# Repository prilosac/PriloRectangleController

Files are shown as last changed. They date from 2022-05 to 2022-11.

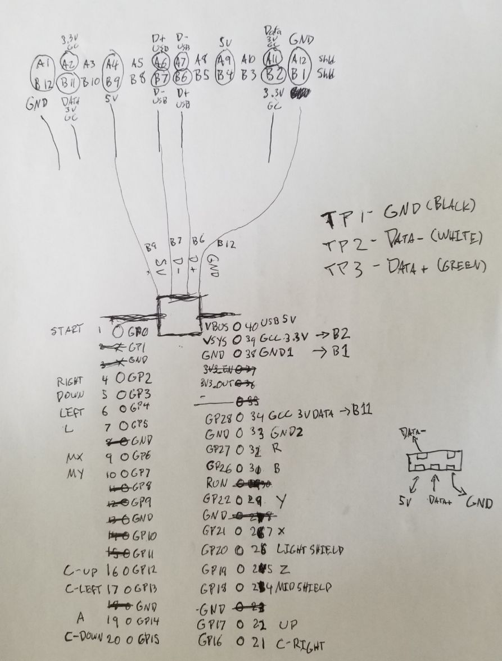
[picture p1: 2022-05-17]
RPiPico-USBC.jpg

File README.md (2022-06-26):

# PriloRectangleController
A digital controller PCB/chassis design meant to be easy to order and assemble while remaining a professional feeling and relatively customizable product.

HEAVILY inspired by GCCMX from Crane1195, which this repository was forked from.

ToDo: Replace these images with images made from this repository's files (these are from Crane's original repo)




The PCB is design to allow easy surface mount soldering of a Raspberry Pi Pico, the preferred board for DIY rectangle controllers in the community currently. It is also designed to easily solder a [Model U](https://github.com/Crane1195/Model-U) to with headers.

Credit to RMZ Customs for the hand drawn Pico diagram, and Austin for the modified Pico kicad files (and for lots of help in general).

## Parts:
1. [2.54mm pitch low profile header](https://www.digikey.com/en/products/detail/samtec-inc/TLW-136-05-T-S/1105024) (allows for thinner rectangle. alternatively use regular (2.50mm insulatio height) headers and allow for an extra 0.98mm of clearance in the case)
2. [M6 size fastener bolts](https://www.amazon.com/gp/product/B07QF7VB9P/ref=ppx_yo_dt_b_asin_title_o00_s00?ie=UTF8&th=1)

## License
This project is licenced under the GNU GPL Version 3. [See the included LICENSE file for details](LICENSE).

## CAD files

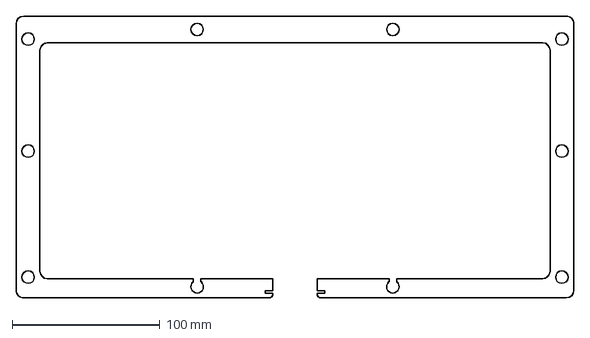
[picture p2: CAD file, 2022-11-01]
src/chassis/4+5_GenericWallLayer-USBCCutout.dxf
377.2 x 190.6 mm

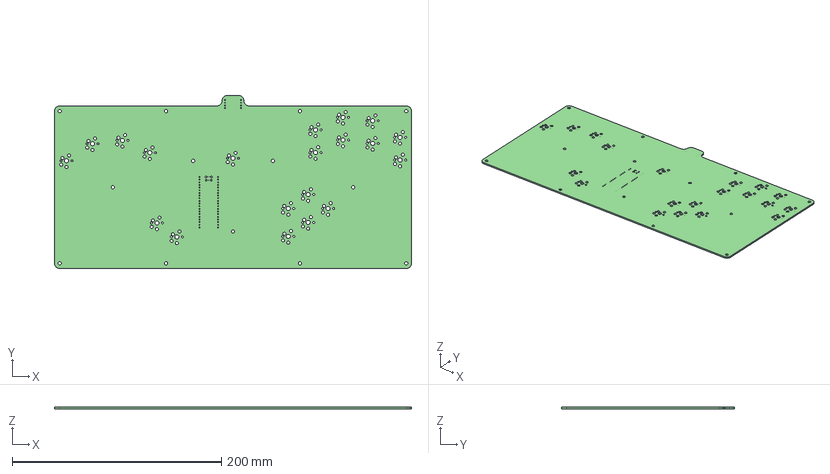
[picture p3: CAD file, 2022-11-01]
src/pcb/GCCMX.step
341.2 x 165.5 x 1.60 mm

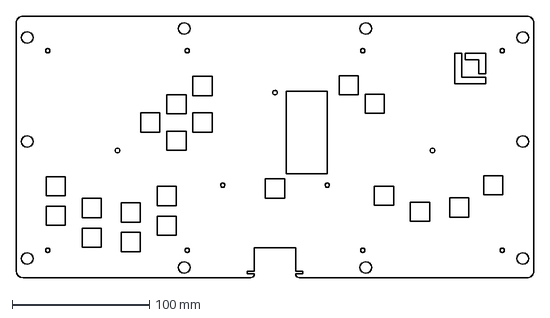
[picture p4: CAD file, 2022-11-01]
src/chassis/3_SwitchPlateOneStartPicoCutout.dxf
377.2 x 190.6 mm

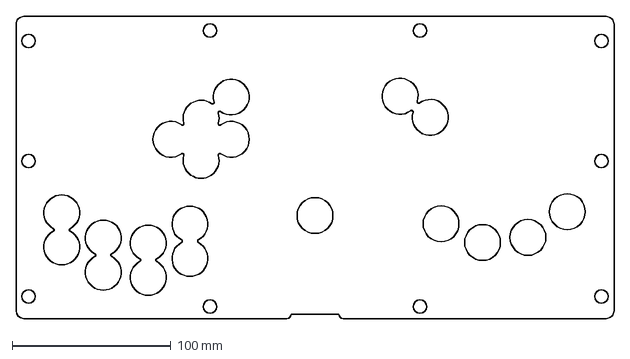
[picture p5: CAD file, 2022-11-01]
src/chassis/1_GFCoverOneStart.dxf
377.2 x 190.6 mm

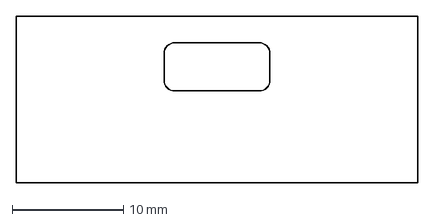
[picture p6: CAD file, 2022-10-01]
src/chassis/USBC_Cutout.dxf
36.0 x 14.9 mm

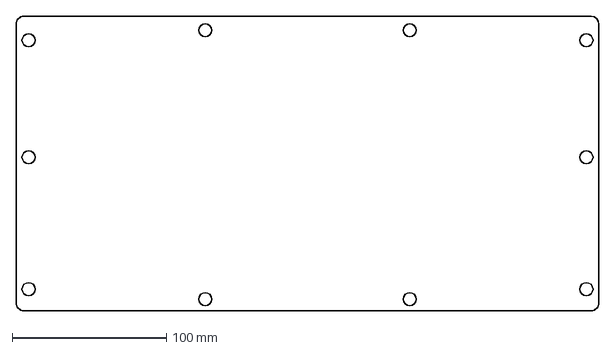
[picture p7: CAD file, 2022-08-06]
src/chassis/6_Bottom.dxf
377.2 x 190.6 mm

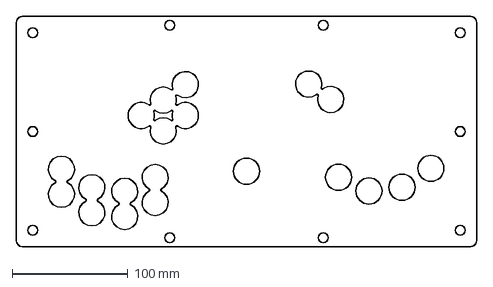
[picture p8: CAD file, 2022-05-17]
src/chassis/1_GFCoverOneStartWithFloatingPiece.dxf
397.2 x 198.6 mm

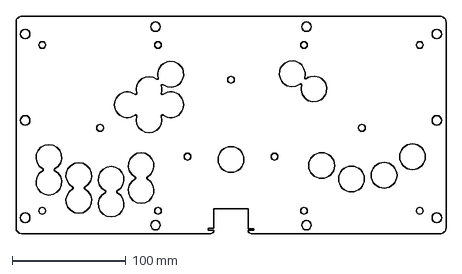
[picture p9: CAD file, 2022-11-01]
src/chassis/1_GFCoverOneStartBottomSwitchplateScrewHoles.dxf
377.2 x 190.6 mm

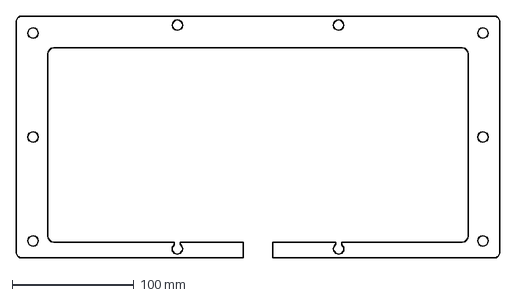
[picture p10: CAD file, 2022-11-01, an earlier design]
src/chassis/old/4+5_GenericWallLayer.dxf
397.2 x 198.6 mm

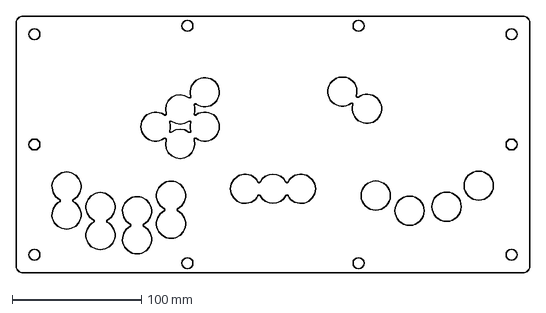
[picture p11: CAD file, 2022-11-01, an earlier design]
src/chassis/old/1_GFCover.dxf
397.2 x 198.6 mm

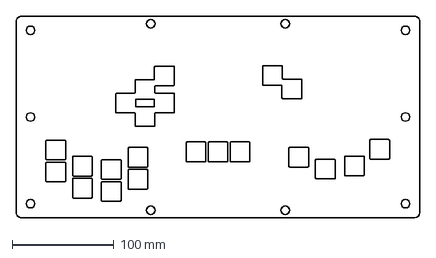
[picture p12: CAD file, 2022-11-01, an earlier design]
src/chassis/old/1_SquareCover.dxf
397.2 x 198.6 mm

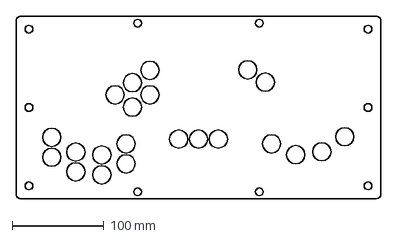
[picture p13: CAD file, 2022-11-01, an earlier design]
src/chassis/old/1_SmallCover.dxf
397.2 x 198.6 mm

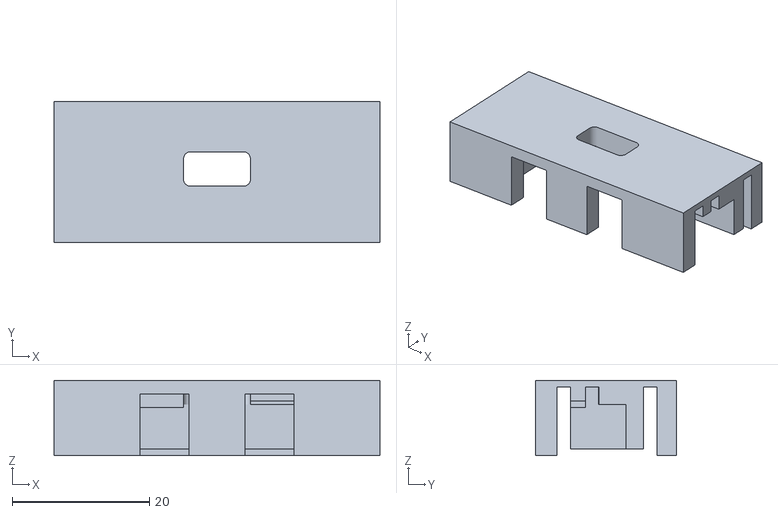
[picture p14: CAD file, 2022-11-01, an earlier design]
src/chassis/old/ModelS_USBC_Cover.stl
47.5 x 20.5 x 11.0

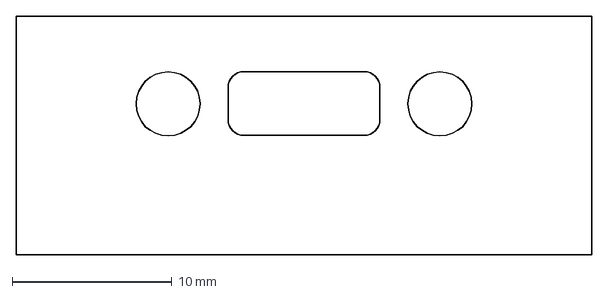
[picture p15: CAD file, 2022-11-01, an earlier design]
src/chassis/old/USBC_CutoutOLD.dxf
36.0 x 14.9 mm

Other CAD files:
src/chassis/old/3_SwitchPlate.dxf
src/chassis/old/4_GCCMXCover.dxf
src/chassis/old/5_ModelSCover.dxf

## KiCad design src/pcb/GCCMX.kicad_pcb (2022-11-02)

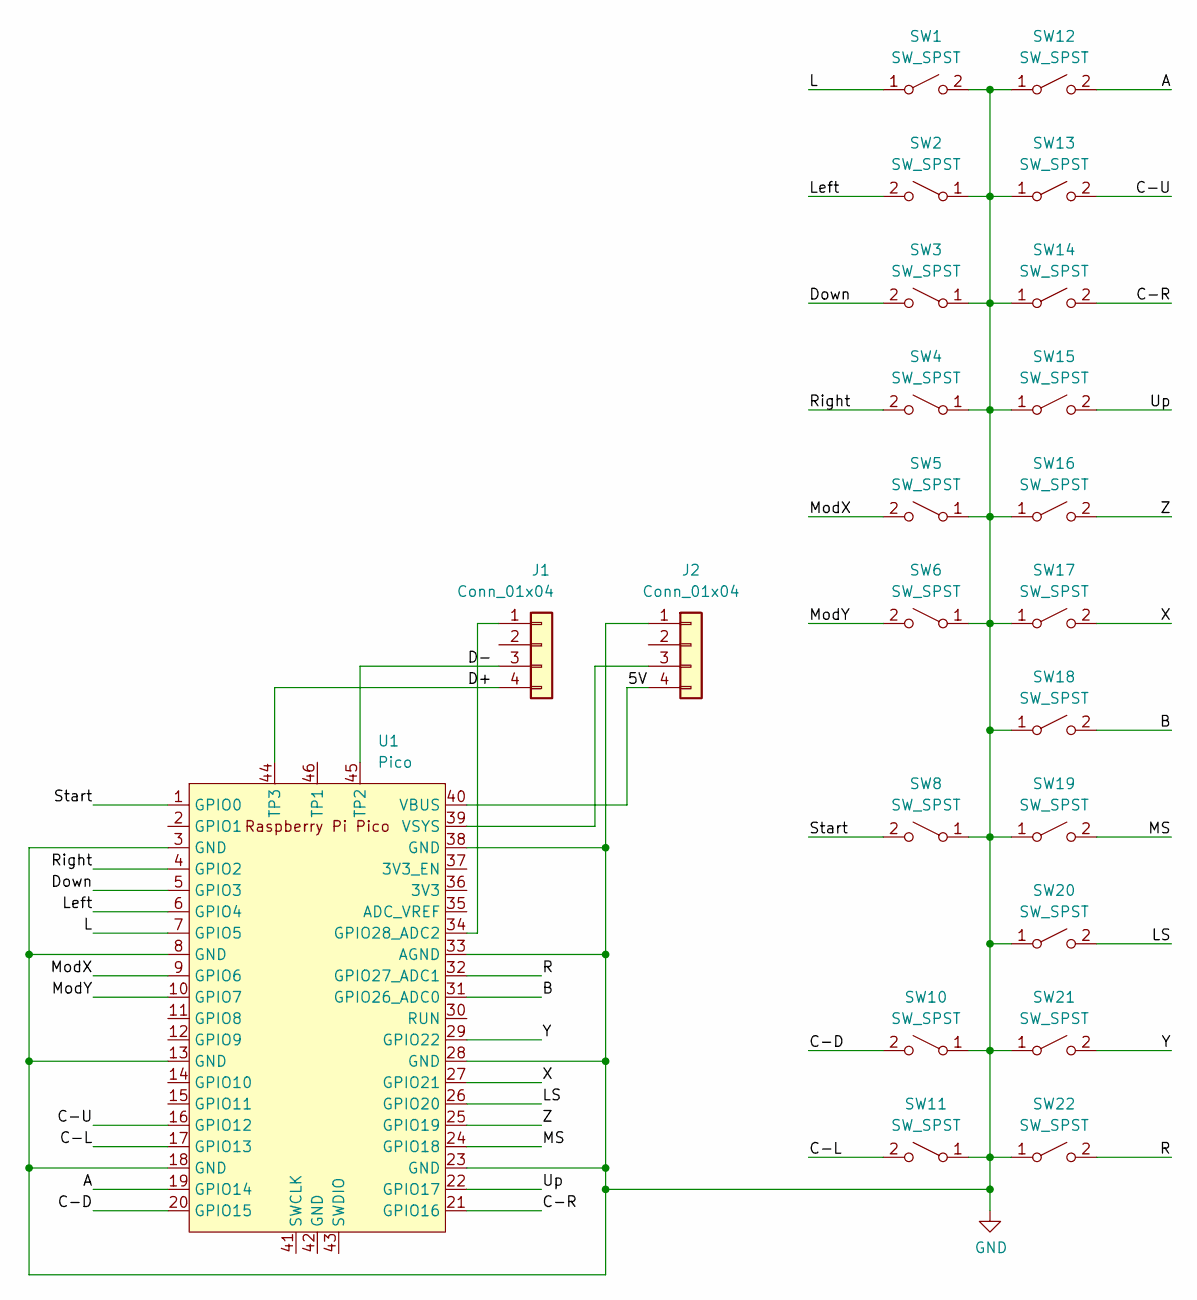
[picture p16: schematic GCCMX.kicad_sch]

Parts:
J1, J2: Conn_01x04; PinHeader_1x04_P2.54mm_Vertical
SW1, SW2, SW3, SW4, SW5, SW6, SW8, SW10, SW11, SW12, SW13, SW14, SW15, SW16, SW17, SW18, SW19, SW20, SW21, SW22: SW_SPST; Kailh_socket_MX+PG1350
U1: Pico; RPi_Pico_Removed3Pins

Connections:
/5V: J2.4, U1.40 (VBUS)
/A: SW12.2 (B), U1.19 (GPIO14)
/B: SW18.2 (B), U1.31 (GPIO26_ADC0)
/C-D: SW10.2 (B), U1.20 (GPIO15)
/C-L: SW11.2 (B), U1.17 (GPIO13)
/C-R: SW14.2 (B), U1.21 (GPIO16)
/C-U: SW13.2 (B), U1.16 (GPIO12)
/D+: J1.4, U1.44 (TP3)
/D-: J1.3, U1.45 (TP2)
/Down: SW3.2 (B), U1.5 (GPIO3)
/L: SW1.1 (A), U1.7 (GPIO5)
/LS: SW20.2 (B), U1.26 (GPIO20)
/Left: SW2.2 (B), U1.6 (GPIO4)
/MS: SW19.2 (B), U1.24 (GPIO18)
/ModX: SW5.2 (B), U1.9 (GPIO6)
/ModY: SW6.2 (B), U1.10 (GPIO7)
/R: SW22.2 (B), U1.32 (GPIO27_ADC1)
/Right: SW4.2 (B), U1.4 (GPIO2)
/Start: SW8.2 (B), U1.1 (GPIO0)
/Up: SW15.2 (B), U1.22 (GPIO17)
/X: SW17.2 (B), U1.27 (GPIO21)
/Y: SW21.2 (B), U1.29 (GPIO22)
/Z: SW16.2 (B), U1.25 (GPIO19)
GND: J2.1, SW1.2 (B), SW2.1 (A), SW3.1 (A), SW4.1 (A), SW5.1 (A), SW6.1 (A), SW8.1 (A), SW10.1 (A), SW11.1 (A), SW12.1 (A), SW13.1 (A), SW14.1 (A), SW15.1 (A), SW16.1 (A), SW17.1 (A), SW18.1 (A), SW19.1 (A), SW20.1 (A), SW21.1 (A), SW22.1 (A), U1.3 (GND), U1.8 (GND), U1.13 (GND), U1.18 (GND), U1.23 (GND), U1.28 (GND), U1.33 (AGND), U1.38 (GND)
unnamed: J1.1, U1.34 (GPIO28_ADC2)
unnamed: J2.3, U1.39 (VSYS)

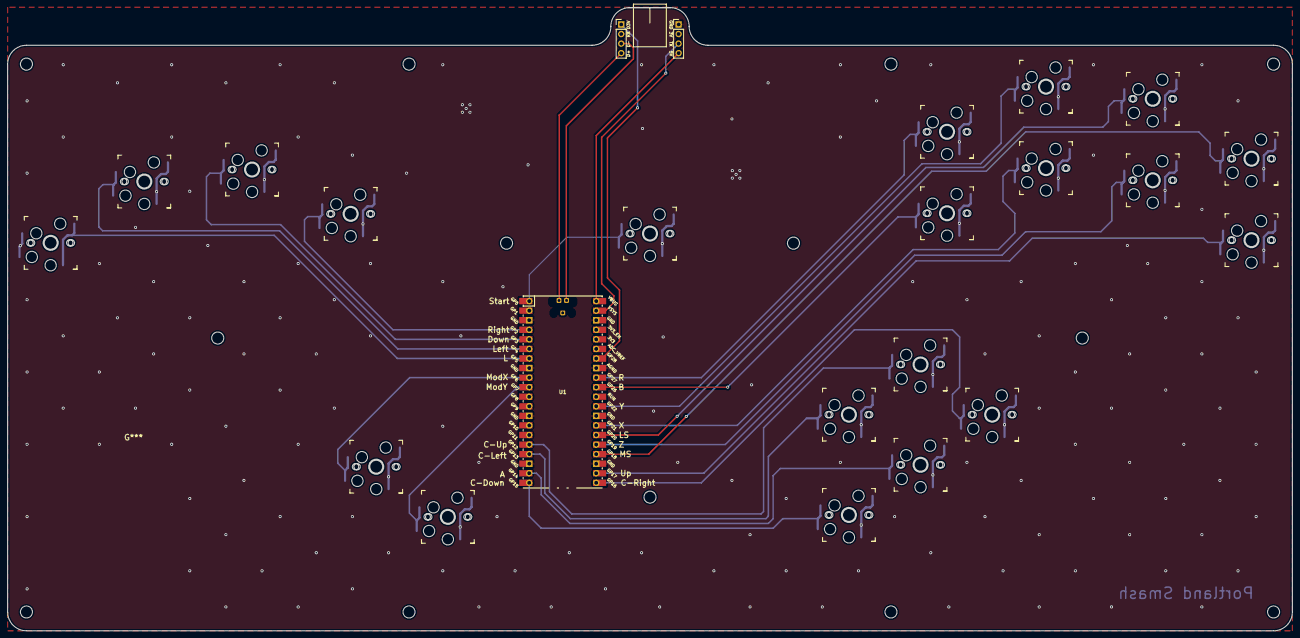
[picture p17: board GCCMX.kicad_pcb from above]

Board: 2 copper layers, 341.2 x 165.5 mm, 23 parts (0 on the bottom side), 26 nets.

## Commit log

2022-05-17 pushing everything up from prior work
    [1_GFCoverOneStart.dxf, 1_GFCoverOneStartBottomSwitchplateScrewHoles.dxf, 1_GFCoverOneStartWithFloatingPiece.dxf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]
2022-06-26 updated wall layers and usbc for a bit more support
    [4+5_GenericWallLayer-USBCCutout.dxf, USBC_Cutout.dxf]
2022-08-06 updated pcb, moved USB to front so we no longer require a separate passthrough cable
    [GCCMX-B_Cu.gbl, GCCMX-B_Mask.gbs, GCCMX-B_Paste.gbp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]
2022-08-06 reduced overall size of case by 20mm horizontally and 8mm vertically, adjusted fastener bolt holes in accordance.
    [1_GFCoverOneStart.dxf, 1_GFCoverOneStartBottomSwitchplateScrewHoles.dxf, 3_SwitchPlateOneStartPicoCutout.dxf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]
2022-11-01 looots of case updates. just need to flip the model UD from the back to the front and im ready to test v3 i think
    [1_GFCover.dxf, 1_GFCoverOneStart.dxf, 1_GFCoverOneStartBottomSwitchplateScrewHoles.dxf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]
2022-11-02 updated PCB to have model UD on top, regenerated fab files
    [GCCMX-B_Cu.gbl, GCCMX-B_Mask.gbs, GCCMX-B_Paste.gbp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]
